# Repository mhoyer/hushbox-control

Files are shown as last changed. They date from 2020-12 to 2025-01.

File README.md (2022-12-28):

# ESP32 - Fan Control

## Resources

### ESP32 Pin Out

- [ESP32 - General Pinout](https://randomnerdtutorials.com/esp32-pinout-reference-gpios/)
- [Doit ESP32 DevKit - Pinout](https://github.com/playelek/pinout-doit-32devkitv1)

### Fan Control

- [ESP32 Fan Controller](https://github.com/KlausMu/esp32-fan-controller)
- [4-Wire PWM Controlled Fans - Pinout](https://allpinouts.org/pinouts/connectors/motherboards/motherboard-cpu-4-pin-fan/)
- [How to read RPM from 3-wire fan](https://electronics.stackexchange.com/a/214082)
- [Raspberry Pi - Building a PWM Fan Controller with DotNet IoT](http://blog.timwheeler.io/building-a-pwm-fan-controller-with-dotnet-iot/)
- [IRLML2502 - MOSFET for switching the fan on/off](https://www.infineon.com/dgdl/irlml2502pbf.pdf)
- [0x1A Transistor (MOSFET) als Schalter](https://www.youtube.com/watch?v=d1yEUiCsBWc)

### Temperature Reading

- [Dallas DS18B20 - 1-Wire Digital Thermometer](https://datasheets.maximintegrated.com/en/ds/DS18B20.pdf)
- [Interfacing DS18B20 1-Wire Digital Temperature Sensor with Arduino](https://lastminuteengineers.com/ds18b20-arduino-tutorial/)

## Micropython

Flashing the firmware:

1. Press and hold the BOOT button and run: `esptool.py --chip esp32 --port /dev/ttyUSB0 erase_flash`
2. Now run: `esptool.py --chip esp32 --port /dev/ttyUSB0 --baud 460800 write_flash -z 0x1000 esp32-idf4-20200902-v1.13.bin`

I tested `esp32-idf4-20191220-v1.12.bin` and `esp32-idf4-20191220-v1.13.bin` from https://micropython.org/download/esp32/.

### Getting infos about ESP32

While the ESP32 is connected to the serial adaptor you can run this `esptool` command and instantly have to press the `BOOT` button on the ESP32:

```bash
$ ./esptool --baud 921600 flash_id
esptool.py v4.4
Found 1 serial ports
Serial port /dev/ttyUSB0
Connecting....
Detecting chip type... Unsupported detection protocol, switching and trying again...
Connecting....
Detecting chip type... ESP32
Chip is ESP32-D0WDQ6 (revision v1.0)
Features: WiFi, BT, Dual Core, Coding Scheme None
Crystal is 40MHz
MAC: 24:0a:c4:13:9a:90
Uploading stub...
Running stub...
Stub running...
Changing baud rate to 921600
Changed.
Manufacturer: c8
Device: 4016
Detected flash size: 4MB
Hard resetting via RTS pin...
```

#### Reading out the existing memory as a backup

```bash
./esptool --baud 921600 read_flash 0 0x400000 backup.bin
```

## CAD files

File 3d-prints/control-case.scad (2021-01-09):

pcb_w = 57.15;
pcb_l = 53.34;
pcb_thickness = 1.55;
pcb_corner_r = 2.29;
pcb_hole_r = 1.35;
pcb_hole_dist = 2.67;
pcb_hole_ul_x = 11.05;
pcb_hole_ul_y = 7.11;

ctrl_h = 17.4;
ctrl_bottom_pins_h = 2;

wall_thickness = 1.2; // 3x0.4

$fn=30;

// Derived values
dome_r = pcb_hole_dist + wall_thickness;
dome_h = ctrl_bottom_pins_h + 1;

case_pcb_gap = 0.5;
case_w_overlap = 6;
case_l = pcb_l + 2*case_pcb_gap;
case_w = pcb_w + 2*case_pcb_gap + 2*case_w_overlap;
case_bottom_h = ctrl_h + dome_h;
case_top_h = 1;

// print_bottom();
// print_bottom_preview();
print_top();
// show_both();

module rounded_hole(w, h, thickness=wall_thickness/2) {
  translate([0,0,-2*thickness])
    linear_extrude(5*thickness)
      offset(r=thickness)
        square([w, h]);
}

module rotate_about_pt(a, v, pt) {
  translate(pt)
    rotate(a,v)
      translate(-pt)
        children();
}

module CaseEdge(pos, h, thickness) {
  translate(pos) union() {
    difference() {
      sphere(r=thickness);
      translate([0,0,thickness])
        cube([2*thickness,2*thickness,2*thickness], center=true);
    }
    translate([0,0,h - 0.1]) cylinder(r=thickness, h=0.1);
  }
}

module RoundedBoxCase(w, l, h, thickness) {
  difference() {
    hull() {
      CaseEdge([0, 0], h, thickness);
      CaseEdge([0, l], h, thickness);
      CaseEdge([w, 0], h, thickness);
      CaseEdge([w, l], h, thickness);
    }
    cube([w, l, 2*h]);
  }
}

module Holes() {
  pcb_dome_offset = pcb_thickness + dome_h;

  translate([case_pcb_gap, case_pcb_gap, pcb_dome_offset]) union() {
    // TMP TO-92 (DS18B20)
    temp_hole_w = 6;
    temp_hole_h = 4;
    temp_hole_x = 17;
    temp_hole_z = 0;

    translate([temp_hole_x, 0, temp_hole_z])
      rotate([90])
        rounded_hole(temp_hole_w, temp_hole_h);

    // IR_IN
    ii_hole_w = 9.95;
    ii_hole_h = 6;
    ii_hole_x = 28.5;
    ii_hole_z = 0;

    translate([ii_hole_x, 0, ii_hole_z])
      rotate([90])
        rounded_hole(ii_hole_w, ii_hole_h);

    // IR_OUT 1
    io1_hole_w = 7.4;
    io1_hole_h = 6;
    io1_hole_x = 40.8;
    io1_hole_z = 0;

    translate([io1_hole_x, 0, io1_hole_z])
      rotate([90])
        rounded_hole(io1_hole_w, io1_hole_h);

    // Power hole
    pwr_hole_w = 8.95;
    pwr_hole_h = 8.95;
    pwr_hole_x = 14.0;
    pwr_hole_z = 11 - pwr_hole_h;

    translate([pwr_hole_x, case_l, pwr_hole_z])
      rotate([90])
        rounded_hole(pwr_hole_w, pwr_hole_h);

    // IR_OUT 2
    io2_hole_w = 7.4;
    io2_hole_h = 6;
    io2_hole_x = 40.8;
    io2_hole_z = 0;

    translate([io2_hole_x, case_l, io2_hole_z])
      rotate([90])
        rounded_hole(io2_hole_w, io2_hole_h);

    // USB
    usb_hole_w = 7.56;
    usb_hole_h = 2.92;
    usb_hole_x = 34.5;
    usb_hole_z = 12.45;

    translate([usb_hole_x, case_l, usb_hole_z])
      rotate([90])
        rounded_hole(io2_hole_w, io2_hole_h, wall_thickness);

    // Switch
    switch_w = 13;
    switch_x = 33.8;
    switch_z = 11.92 / 2;
    switch_r = 3.2; // d=5.92

    translate([switch_x, case_l+2*wall_thickness, switch_z])
      rotate([90])
        cylinder(r=switch_r, h=3*wall_thickness);
  }
}

module Bottom() {
  translate([wall_thickness, wall_thickness, wall_thickness])
    difference() {
      union() {
        translate([-case_w_overlap,0,0])
          RoundedBoxCase(case_w, case_l, case_bottom_h, wall_thickness);

        // domes
        translate([case_pcb_gap, case_pcb_gap]) union() {
          translate([pcb_hole_dist, pcb_hole_dist])             cylinder(r=dome_r, h=dome_h);
          translate([pcb_hole_ul_x, pcb_l-pcb_hole_ul_y])       cylinder(r=dome_r, h=dome_h);
          translate([pcb_w-pcb_hole_dist, pcb_l-pcb_hole_dist]) cylinder(r=dome_r, h=dome_h);
          translate([pcb_w-pcb_hole_dist, pcb_hole_dist])       cylinder(r=dome_r, h=dome_h);
        }
      }

      translate([case_pcb_gap, case_pcb_gap]) union() {
        // screw holes
        screw_r = 1.5;
        translate([pcb_hole_dist, pcb_hole_dist, -2*wall_thickness])
          cylinder(r=screw_r, h=dome_h+4*wall_thickness);
        translate([pcb_hole_ul_x, pcb_l - pcb_hole_ul_y, -2*wall_thickness])
          cylinder(r=screw_r, h=dome_h+4*wall_thickness);
        translate([pcb_w - pcb_hole_dist, pcb_l - pcb_hole_dist, -2*wall_thickness])
          cylinder(r=screw_r, h=dome_h+4*wall_thickness);
        translate([pcb_w - pcb_hole_dist, pcb_hole_dist, -2*wall_thickness])
          cylinder(r=screw_r, h=dome_h+4*wall_thickness);

        // nut sinks
        nut_d = 5.2; // orig: d=4.92;
        nut_ro = nut_d/sqrt(3);
        nut_h = 2; // orog: 1.82
        translate([pcb_hole_dist, pcb_hole_dist, -wall_thickness-0.01])
          cylinder(r=nut_ro, h=nut_h, $fn=6);
        translate([pcb_hole_ul_x, pcb_l - pcb_hole_ul_y, -wall_thickness-0.01])
          cylinder(r=nut_ro, h=nut_h, $fn=6);
        translate([pcb_w - pcb_hole_dist, pcb_l - pcb_hole_dist, -wall_thickness-0.01])
          cylinder(r=nut_ro, h=nut_h, $fn=6);
        translate([pcb_w - pcb_hole_dist, pcb_hole_dist, -wall_thickness-0.01])
          cylinder(r=nut_ro, h=nut_h, $fn=6);

        // floor holes
        floor_hole_d = 5;
        for (x=[0:5]) {
          translate([pcb_w * (x+1.5)/8, pcb_l * 0.5/8, -2*wall_thickness])
            cylinder(d=floor_hole_d, h=3*wall_thickness);
        }

        for (y=[1:2:5]) for (x=[0:8]) {
          translate([pcb_w * x/8, pcb_l * (y+0.5)/8, -2*wall_thickness])
            cylinder(d=floor_hole_d, h=3*wall_thickness);
        }

        for (y=[2:2:4]) for (x=[1:8]) {
          translate([pcb_w * (x-0.5)/8, pcb_l * (y+0.5)/8, -2*wall_thickness])
            cylinder(d=floor_hole_d, h=3*wall_thickness);
        }

        translate([pcb_w * (0.5)/8, pcb_l * (6.5)/8, -2*wall_thickness])
          cylinder(d=floor_hole_d, h=3*wall_thickness);

        for (x=[3:8]) {
          translate([pcb_w * (x-0.5)/8, pcb_l * (6.5)/8, -2*wall_thickness])
            cylinder(d=floor_hole_d, h=3*wall_thickness);
        }

        for (x=[3:6]) {
          translate([pcb_w * (x)/8, pcb_l * (7.5)/8, -2*wall_thickness])
            cylinder(d=floor_hole_d, h=3*wall_thickness);
        }
      }

      Holes();

      // wallmount holes
      wm_screw_d = 3;
      translate([-0.5*case_w_overlap, case_w_overlap, -2*wall_thickness])
        cylinder(d = wm_screw_d + 0.1, h = 4*wall_thickness);
      translate([-0.5*case_w_overlap, case_l - case_w_overlap, -2*wall_thickness])
        cylinder(d = wm_screw_d + 0.1, h = 4*wall_thickness);
      translate([case_w - 1.5*case_w_overlap, case_w_overlap, -2*wall_thickness])
        cylinder(d = wm_screw_d + 0.1, h = 4*wall_thickness);
      translate([case_w - 1.5*case_w_overlap, case_l - case_w_overlap, -2*wall_thickness])
        cylinder(d = wm_screw_d + 0.1, h = 4*wall_thickness);
    }
}

module Top() {
  inlet_h = 3;

  translate([wall_thickness, wall_thickness, -case_top_h-wall_thickness])
    difference() {
      translate([0, 0, case_top_h])
        difference() {
          translate([-case_w_overlap, 0, 0])
          rotate_about_pt([0,180,0], pt=[case_w/2, case_l/2])
          union() {
            // Outer box
            RoundedBoxCase(case_w, case_l, case_top_h, wall_thickness);

            // Inlet
            difference() {
              hull() {
                cube([case_w, case_l, case_top_h + inlet_h]);
                translate([inlet_h/4, inlet_h/4])
                  cube([
                    case_w - inlet_h/2,
                    case_l - inlet_h/2,
                    case_top_h + 1.5*inlet_h]);
              }

              translate([wall_thickness, wall_thickness, -1])
                cube([
                  case_w - 2*wall_thickness,
                  case_l - 2*wall_thickness,
                  2*(case_top_h+inlet_h)
                ]);
            }
          }

          // Fan holes:
          fan_hole_w = 5.72;
          fan_hole_h = 22;
          fan_hole_x = 5.93;
          fan_hole_y = 4.92;

          translate([
              fan_hole_x - wall_thickness + case_pcb_gap,
              fan_hole_y - wall_thickness + case_pcb_gap,
              0])
            rounded_hole(fan_hole_w, fan_hole_h);

          // ESP
          esp_hole_w = 28.15 + 2;
          esp_hole_l = case_w + 2;
          esp_hole_x = 24.37;
          translate([esp_hole_x-1, -1, -case_top_h-0.1])
            mirror([0,0,1])
              cube([esp_hole_w, esp_hole_l, case_bottom_h]);

          // top holes
          floor_hole_d = 4;

          translate([-case_w_overlap, 0, 0]) {
            for (x=[4:6]) for (y=[1:5]) {
              x = y % 2 ? x : x-0.5;
              if (x >= 2) {
                translate([case_w * (x+0.5)/8, case_l * (y+0.5)/7, -2*wall_thickness])
                  cylinder(d=floor_hole_d, h=3*wall_thickness);
              }
            }
          }
        }
      Holes();
    }
}

module print_bottom() {
  translate([0, 5])
    Bottom();
}
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

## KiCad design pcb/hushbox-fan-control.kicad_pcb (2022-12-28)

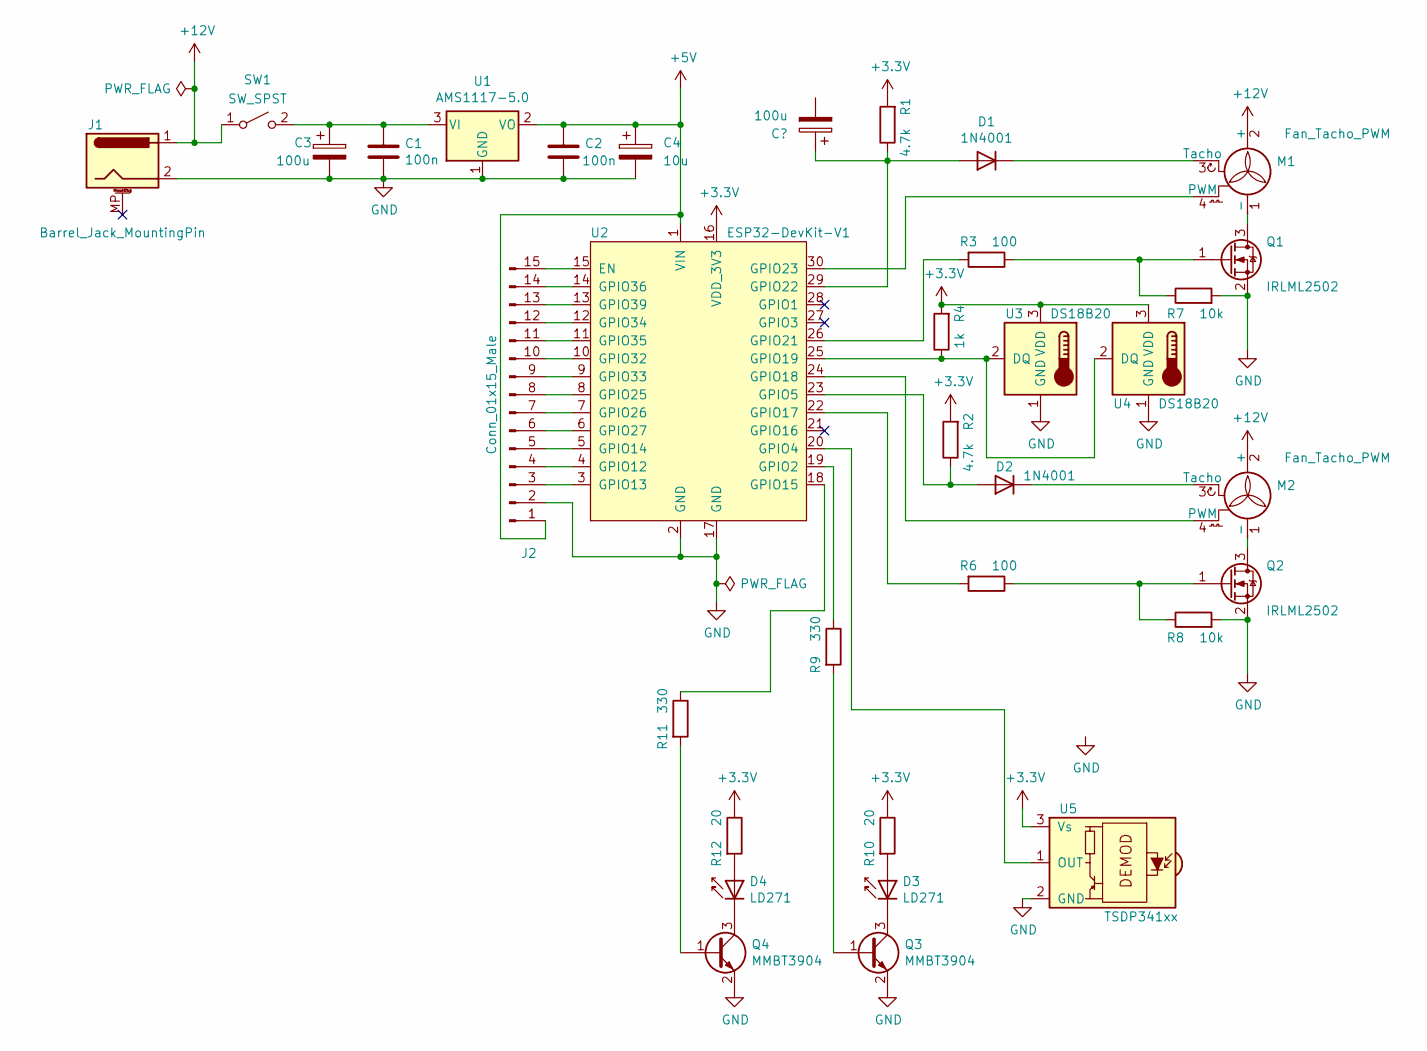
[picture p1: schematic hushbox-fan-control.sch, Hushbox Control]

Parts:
C1, C2: 100n; C_0805_2012Metric_Pad1.18x1.45mm_HandSolder
C3: 100u; CP_Radial_D8.0mm_P2.50mm
C4: 10u; CP_Radial_D5.0mm_P2.50mm
D1, D2: 1N4001; D_SMA_Handsoldering
D3, D4: LD271; JST_XH_S2B-XH-A_1x02_P2.50mm_Horizontal
J1: Barrel_Jack_MountingPin; BarrelJack_Horizontal
J2: Conn_01x15_Male; PinSocket_1x15_P2.54mm_Vertical
M1, M2: Fan_Tacho_PWM; FanPinHeader_1x04_P2.54mm_Vertical
Q1, Q2: IRLML2502; SOT-23_Handsoldering
Q3, Q4: MMBT3904; SOT-23_Handsoldering
R1, R2: 4.7k; R_0805_2012Metric_Pad1.20x1.40mm_HandSolder
R3, R6: 100; R_0805_2012Metric_Pad1.20x1.40mm_HandSolder
R4: 1k; R_0805_2012Metric_Pad1.20x1.40mm_HandSolder
R7, R8: 10k; R_0805_2012Metric_Pad1.20x1.40mm_HandSolder
R9, R11: 330; R_0805_2012Metric_Pad1.20x1.40mm_HandSolder
R10, R12: 20; R_0805_2012Metric_Pad1.20x1.40mm_HandSolder
SW1: SW_SPST; PinSocket_1x02_P2.54mm_Vertical
U1: AMS1117-5.0; SOT-223-3_TabPin2
U2: ESP32-DevKit-V1; Doit_ESP32_DevKit_V1
U3, U4: DS18B20; JST_XH_B3B-XH-A_1x03_P2.50mm_Vertical
U5: TSDP341xx; JST_XH_S3B-XH-A_1x03_P2.50mm_Horizontal

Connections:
+3V3: R1.2, R2.2, R4.2, R10.1, R12.1, U2.16 (VDD_3V3), U3.3 (VDD), U4.3 (VDD), U5.3 (Vs); also elsewhere on the board
+5V: C2.1, C4.1, J2.1, U1.2 (VO), U2.1 (VIN)
+12V: J1.1, M1.2 (+), M2.2 (+), SW1.1 (A)
GND: C1.2, C2.2, C3.2, C4.2, J1.2, J2.2, Q1.2 (S), Q2.2 (S), Q3.2 (E), Q4.2 (E), R7.2, R8.2, U1.1 (GND), U2.2 (GND), U2.17 (GND), U3.1 (GND), U4.1 (GND), U5.2 (GND)
unnamed: C1.1, C3.1, SW1.2 (B), U1.3 (VI)
unnamed: D1.1 (K), M1.3 (Tacho)
unnamed: D1.2 (A), R1.1, U2.29 (GPIO22)
unnamed: D2.1 (K), M2.3 (Tacho)
unnamed: D2.2 (A), R2.1, U2.23 (GPIO5)
unnamed: D3.1 (K), Q3.3 (C)
unnamed: D3.2 (A), R10.2
unnamed: D4.1 (K), Q4.3 (C)
unnamed: D4.2 (A), R12.2
unnamed: J2.3, U2.3 (GPIO13)
unnamed: J2.4, U2.4 (GPIO12)
unnamed: J2.5, U2.5 (GPIO14)
unnamed: J2.6, U2.6 (GPIO27)
unnamed: J2.7, U2.7 (GPIO26)
unnamed: J2.8, U2.8 (GPIO25)
unnamed: J2.9, U2.9 (GPIO33)
unnamed: J2.10, U2.10 (GPIO32)
unnamed: J2.11, U2.11 (GPIO35)
unnamed: J2.12, U2.12 (GPIO34)
unnamed: J2.13, U2.13 (GPIO39)
unnamed: J2.14, U2.14 (GPIO36)
unnamed: J2.15, U2.15 (EN)
unnamed: M1.1 (-), Q1.3 (D)
unnamed: M1.4 (PWM), U2.30 (GPIO23)
unnamed: M2.1 (-), Q2.3 (D)
unnamed: M2.4 (PWM), U2.24 (GPIO18)
unnamed: Q1.1 (G), R3.1, R7.1
unnamed: Q2.1 (G), R6.1, R8.1
unnamed: Q3.1 (B), R9.2
unnamed: Q4.1 (B), R11.2
unnamed: R3.2, U2.26 (GPIO21)
unnamed: R4.1, U2.25 (GPIO19), U3.2 (DQ), U4.2 (DQ)
unnamed: R6.2, U2.22 (GPIO17)
unnamed: R9.1, U2.19 (GPIO2)
unnamed: R11.1, U2.18 (GPIO15)
unnamed: U2.20 (GPIO4), U5.1 (OUT)

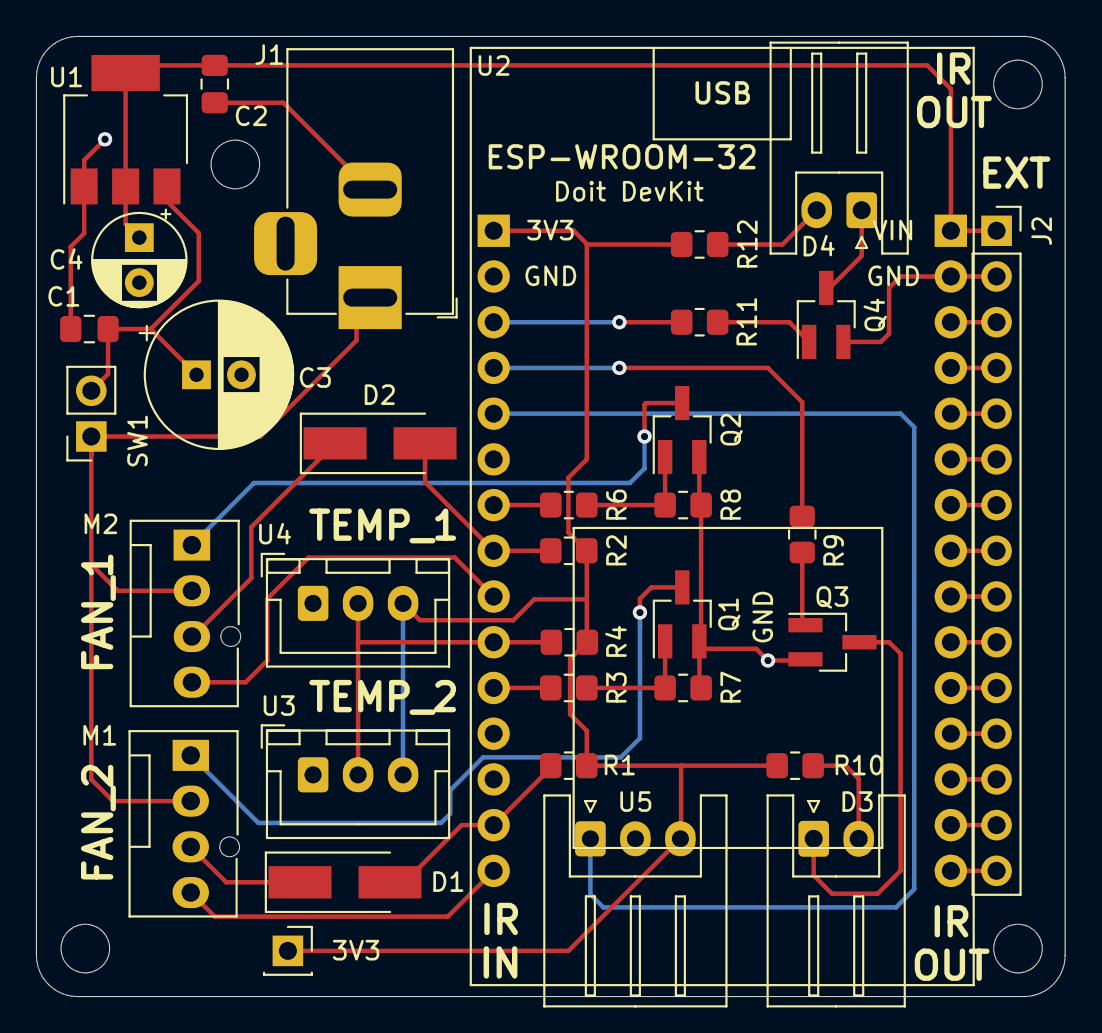
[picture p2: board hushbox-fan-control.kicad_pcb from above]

Board: 2 copper layers, 57.1 x 53.3 mm, 34 parts (0 on the bottom side), 40 nets.

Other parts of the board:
3V3: PinSocket_1x01_P2.54mm_Vertical

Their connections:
+3V3: 3V3.1; also elsewhere on the board

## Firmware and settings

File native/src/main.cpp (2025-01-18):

#include <Arduino.h>

#include "config.h"
#include "ota.h"
#include "./WiFiCnx/WiFiCnx.h"
#include "./MqttCtrl/MqttCtrl.h"
#include "ir-io.h"
#include "linear-fan-speed.h"
#include "rpm-reader.h"
#include "temperatures-reader.h"

WiFiCnx *wiFiCnx;
MqttCtrl *mqtt;
lfs_t lfs_in, lfs_out;

void set_movie_mode(String payload)
{
    Serial.println("Setting movie mode " + payload);

    if (strcmp(payload.c_str(), "on") == 0)
    {
        IR::turnReceiverOn();
        IR::turnProjectorOn();
    }
    else if (strcmp(payload.c_str(), "off") == 0)
    {
        IR::turnProjectorOff();
        delay(500);
        IR::turnReceiverOff();
    }
}

void set_fan_mode(String payload)
{
    Serial.println("Setting fan " + payload);

    if (strcmp(payload.c_str(), "on") == 0)
    {
        digitalWrite(CFG_PIN_FAN_SWITCH_IN, HIGH);
        digitalWrite(CFG_PIN_FAN_SWITCH_OUT, HIGH);
    }
    else if (strcmp(payload.c_str(), "off") == 0)
    {
        digitalWrite(CFG_PIN_FAN_SWITCH_IN, LOW);
        digitalWrite(CFG_PIN_FAN_SWITCH_OUT, LOW);
    }
}

void set_fan_speed(String payload)
{
    float speed = ::atof(payload.c_str());
    Serial.println("Setting fan speed to " + payload);

    setSpeedByTemperature(lfs_in, speed);
    setSpeedByTemperature(lfs_out, speed);
}

// payload is: "(i|o) [<IR_CODE>, ...]"
// example: "i 0x5EA1B847 0x5EA1D827"
void send_ir_codes(String payload)
{
    Serial.println("Sending IR codes: " + payload);

    bool use_ir_out = true;
    if (payload.charAt(0) == 'i')
    {
        use_ir_out = false;
    }
    
    Serial.printf("  Using '%s' IR port.\n", use_ir_out ? "out" : "in");

    const char* delim = " ";
    char* token = strtok(&payload[2], delim);

    do
    {
        uint64_t code = strtoull(token, NULL, 16);
        Serial.printf("  Token: %llu\n", code);
        if (use_ir_out)
        {
            IR::send_ir_out(code);
        }
        else
        {
            IR::send_ir_in(code);
        }
    }
    while ((token = strtok(NULL, delim)));
}

void restart(String payload)
{
    esp_restart();
}

void setup()
{
    Serial.begin(115200);

    setupIR(CFG_PIN_IR_RECEIVE, CFG_PIN_IR_SEND_IN, CFG_PIN_IR_SEND_OUT);
    // setupTemperaturesReader(CFG_PIN_TEMP);
    pinMode(CFG_PIN_FAN_SWITCH_IN, OUTPUT);
    pinMode(CFG_PIN_FAN_SWITCH_OUT, OUTPUT);
    pinMode(LED_BUILTIN, OUTPUT);
    setupRPMReader(CFG_PIN_FAN_RPM_IN, CFG_PIN_FAN_RPM_OUT);
    digitalWrite(CFG_PIN_FAN_SWITCH_IN, LOW);
    digitalWrite(CFG_PIN_FAN_SWITCH_OUT, LOW);

    lfs_in.pin = CFG_PIN_FAN_PWM_IN;
    lfs_in.min_temp = 20;
    lfs_in.max_temp = 30;
    lfs_out.pin = CFG_PIN_FAN_PWM_OUT;
    lfs_out.min_temp = 20;
    lfs_out.max_temp = 30;

    setupLinearFanSpeed(lfs_in);
    setupLinearFanSpeed(lfs_out);
    setSpeedByTemperature(lfs_in, 24);
    setSpeedByTemperature(lfs_out, 24);

    wiFiCnx = new WiFiCnx(CFG_HOSTNAME, CFG_WIFI_SSID, CFG_WIFI_PWD);
    wiFiCnx->connect();
    delay(500);
    setupOTA(CFG_HOSTNAME);

    mqtt = new MqttCtrl(*(wiFiCnx->client), CFG_MQTT_SERVER, CFG_HOSTNAME);
    mqtt->connect();
    delay(1000);
    mqtt->subscribe("hushboxctrl/movie_mode", set_movie_mode);
    mqtt->subscribe("hushboxctrl/fan_mode", set_fan_mode);
    mqtt->subscribe("hushboxctrl/fan_speed", set_fan_speed);
    mqtt->subscribe("hushboxctrl/restart", restart);
    mqtt->subscribe("hushboxctrl/send_ir_codes", send_ir_codes);

    Serial.println("Setup done");
}

unsigned long _prev_monitor_millis;
void loop()
{
    wiFiCnx->loop();
    ArduinoOTA.handle();
    mqtt->loop();

    decodeIR();
    // auto temps = readTemperatures();
    auto rpms = readRPMValues();

    // if (millis() > 15000 && millis() < 16000)
    //     setSpeedByTemperature(lfs_in, 25);
    // if (millis() > 40000 && millis() < 41000)
    //     setSpeedByTemperature(lfs_in, 20);
    // if (millis() > 60000 && millis() < 61000)
    //     digitalWrite(CFG_PIN_FAN_SWITCH_IN, LOW);
    //     digitalWrite(CFG_PIN_FAN_SWITCH_OUT, LOW);

    if (millis() - _prev_monitor_millis > 10000)
    {
        _prev_monitor_millis = millis();
        Serial.print(millis());
        
        // Serial.print(" | Temp in=");
        // Serial.print(temps.in);
        // Serial.print("C  out=");
        // Serial.print(temps.out);
        // Serial.print("C");

        Serial.print(" | Fan speed in=");
        Serial.print(rpms.in);
        Serial.print("RPM  out=");
        Serial.print(rpms.out);
        Serial.println("RPM");
        
        digitalWrite(LED_BUILTIN, HIGH);
        delay(20);
        digitalWrite(LED_BUILTIN, LOW);
    }
    yield();
}

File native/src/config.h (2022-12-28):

#ifndef CONFIG_H
#define CONFIG_H

#define CFG_HOSTNAME "hbfc"
#define CFG_WIFI_SSID "XXX"
#define CFG_WIFI_PWD "XXX"
#define CFG_MQTT_SERVER "XXX"

#define CFG_PIN_TEMP 19
#define CFG_PIN_FAN_SWITCH_IN 17
#define CFG_PIN_FAN_SWITCH_OUT 21
#define CFG_PIN_FAN_RPM_IN 5
#define CFG_PIN_FAN_RPM_OUT 22
#define CFG_PIN_FAN_PWM_IN 18
#define CFG_PIN_FAN_PWM_OUT 23
#define CFG_PIN_IR_RECEIVE 4
#define CFG_PIN_IR_SEND_OUT 15
#define CFG_PIN_IR_SEND_IN 2

#endif

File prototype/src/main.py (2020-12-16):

from time import sleep
from linear_fan_control import LinearFanControl
from temp_reader import TempReader
from rpm_reader import RPMReader
from wifi import connect_wifi
from metrics import send_metrics
from machine import Pin

connect_wifi()

lfc_in = LinearFanControl(pwm_pin=23, min_temp=23, max_temp=30)
lfc_out = LinearFanControl(pwm_pin=18, min_temp=23, max_temp=30)

rpm_in = RPMReader(rpm_pin=22)
rpm_out = RPMReader(rpm_pin=5)

temp_reader = TempReader(pin=19)
# temp_reader_2 = TempReader(pin=16)
fan_switch = Pin(21, Pin.OUT)
fan_switch_2 = Pin(17, Pin.OUT)

while True:
    temp = 100
    temp2 = 100
    try:
        temps = list(temp_reader.read_temps())
        temp = temps[0]
        temp2 = temps[1]
    except Exception:
        pass

    if temp < lfc_out.min_temp:
        fan_switch.off()
        print("Temp={:<7}C Temp2={:<7}C".format(temp, temp2))
        send_metrics('temperature temp={}'.format(temp))
    else:
        fan_switch.on()
        lfc_in.update_pwm_for_temp(temp)
        lfc_out.update_pwm_for_temp(temp)

        print("Temp={:<7}C => IN [PWM={:<4} RPM={:<5}] OUT [PWM={:<4} RPM={:<5}]".format(
            temp,
            lfc_in.pwm.duty(), rpm_in.rpm,
            lfc_out.pwm.duty(), rpm_out.rpm))

        send_metrics('\n'.join([
            'temperature temp={}'.format(temp),
            'fan,id=in pwm={},rpm={}'.format(lfc_in.pwm.duty(), rpm_in.rpm),
            'fan,id=out pwm={},rpm={}'.format(lfc_out.pwm.duty(), rpm_out.rpm)
        ]))
    sleep(3)

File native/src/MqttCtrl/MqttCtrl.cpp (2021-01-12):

#include <Arduino.h>
#include <functional>
#include <WiFi.h>
#include <PubSubClient.h>

#include "./MqttCtrl/MqttCtrl.h"

using namespace std::placeholders; // for `_1` in std:bind

MqttCtrl::MqttCtrl(Client &netClient, String mqttServer, String clientId)
{
    this->_netClient = &netClient;
    this->_clientId = clientId;
    this->_server = mqttServer;

    Serial.println("Configuring MQTT client:");
    Serial.println("  server = " + this->_server);
    Serial.println("  client_id = " + clientId);

    this->_pubSubClient = new PubSubClient(netClient);
    this->_pubSubClient->setServer(this->_server.c_str(), 1883);
    this->_pubSubClient->setCallback(std::bind(&MqttCtrl::receivedCallback, this, _1, _2, _3));
}

void MqttCtrl::connect()
{
    this->_reconnect();
}

void MqttCtrl::_reconnect()
{
    if (!this->_pubSubClient->connected())
    {
        if (millis() > 5000 && millis() - this->_lastConnect < 10000)
        {
            return;
        }
        this->_lastConnect = millis();

        this->_pubSubClient = new PubSubClient(*this->_netClient);
        this->_pubSubClient->setServer(this->_server.c_str(), 1883);
        this->_pubSubClient->setCallback(std::bind(&MqttCtrl::receivedCallback, this, _1, _2, _3));

        const char *clientId = this->_clientId.c_str();
        Serial.print("MQTT connecting to ");
        Serial.println(this->_server);
        if (this->_pubSubClient->connect(clientId))
        {
            Serial.println("Connected.");
            return;
        }
        else
        {
            Serial.print("failed, status code = ");
            Serial.print(this->_pubSubClient->state());
            Serial.println(". Try again in next loop.");
            delay(1000);
        }
    }
}

void MqttCtrl::loop()
{
    if (!this->_pubSubClient->connected())
    {
        this->_reconnect();
        this->_resubscribe();
    }
    else
    {
        this->_pubSubClient->loop();
    }
}

void MqttCtrl::subscribe(String topic, TOPIC_RCV_CALLBACK_SIGNATURE cb)
{
    if (this->_pubSubClient->connected() && _subscriptions.find(topic) == _subscriptions.end())
    {
        this->_pubSubClient->subscribe(topic.c_str());
        Serial.print("Subscribed to ");
        Serial.println(topic.c_str());
    }

    _subscriptions.insert({ topic, cb });
}

void MqttCtrl::_resubscribe()
{
    Serial.println("Resubscribing");

    for (const auto &sub : _subscriptions) {
        auto topic = sub.first;
        this->_pubSubClient->subscribe(topic.c_str());
    }
}

void MqttCtrl::receivedCallback(char *topic, byte *payload, unsigned int length)
{
    Serial.print("Message received at: ");
    Serial.println(topic);

    Serial.print("  Payload: ");
    for (int i = 0; i < length; i++)
    {
        Serial.print((char)payload[i]);
    }

    Serial.println();

    if (_subscriptions.find(topic) != _subscriptions.end())
    {
        auto cb = _subscriptions[topic];
        char payload_s[length+1];
        strlcpy(payload_s, (char*)payload, length+1);
        cb(payload_s);
    }
    else {
        Serial.println("  No subscription found for this topic.");
    }
}

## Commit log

2020-11-15 add hushbox PCB with schema and Doit ESP32 DevKit library
    [hushbox-fan-control.kicad_pcb, hushbox-fan-control.sch]
2020-11-15 add support for fan on/off switch
2020-12-16 move python code into prototype subfolder
2020-12-16 improve pcb to v1.1 with IR support
    [hushbox-fan-control.kicad_pcb, hushbox-fan-control.sch]
2021-01-01 add control-case 3d model
    [control-case.scad]
2021-01-02 fix nut holes dimensions and some refactorings
    [control-case.scad]
2021-01-02 add bottom preview helper
    [control-case.scad]
2021-01-02 add switch hole
    [control-case.scad]
2021-01-03 extend case width and add floor and wallmount holes
    [control-case.scad]
2021-01-09 fix tiny holes in dome
    [control-case.scad]
2021-01-09 adjust hole radius to let screws slide in smooth as butter
    [control-case.scad]
2021-01-09 add holes into top cover
    [control-case.scad]
2021-01-13 improve TempReader to pass in pin on `setup`
2021-01-15 add fan switch and binding to MQTT
    [config.h, main.cpp]
2021-01-16 fix RPM and TempReader to have dedicated local `_recent_values` variable
    [TempReader.cpp]
2021-01-17 refactor ota and linear-fan-speed
2021-01-17 refactor temperatures-reader
2022-12-28 finalize PCB layout
    [hushbox-fan-control.kicad_pcb, hushbox-fan-control.sch]
2022-12-28 add some more docs to README about backup of ESP32 memory
2025-01-18 fix build issues after update to latest framework and lib versions (also pinned current working versions)
    [main.cpp]
2026-10-20 refactor MqttCtrl and improve serial prints
